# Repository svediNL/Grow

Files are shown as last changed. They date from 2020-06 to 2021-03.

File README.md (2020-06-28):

# Grow
This project uses a `Python` program in combination with an `Arduino Mega` to monitor and control factors that are involved with plant growth.

It is supposed to be used as an open-source, modular platform for growers that want to find (or create) optimal growing conditions for the growth of their plants.

The main program is started by running `python gui.py`. 
Through GUI:
- User can choose to enable/diable light as well as control intensity 
    - Manual control
    - Automatic configurable day/night cycle
- Pump is controlled with a PWM setpoint (0-255) and has external enable/disable button. 
    - The pump is interlocked (meaning it will stop) when the float switch is open, to prevent overflow or keep water at a certain level.
- Moisture value and temperature values are logged
  - Current values displayed seperatly

On the microcontroller, the following devices can be configured:
- X amount of `moisture sensor`s [Analog Input, Digital Output] 
- X amount of h-brigde `pump`s [2x PWM Outout]
- X amount of water level `float switch`es [Digital Input]
- X amount of `valve relay`s [Digital Output]
- X amount of `NTC thermistor`s [Analog Input]
- X amount of RGBW-channel `LED driver`s [PWM Output]
- Light dimming door switch [Digital Input]

## /Grow
Software suite for plant environment control.

## /Grow/app
Application directory for main application. 

### /Grow/app/config.py
Configuration of the grow setup. 
Device can be defined here and must be in accordance with the configuration installed on the arduino slave (grow.h)

### /Grow/app/gui.py
Main program.

Run in terminal using: `~/Grow/app$ python gui.py`

Dependencies: `matplotlib`, `tkinter`

### /Grow/app/comms.py
Custom library for communication with arduino.

Dependencies: `pySerial`

## /Grow/arduino

### /Grow/arduino/grow.h
Devices are defined here.

## Installing python modules
### matplotlib
`pip install matpotlib`

### pySerial
`pip install pyserial`
``

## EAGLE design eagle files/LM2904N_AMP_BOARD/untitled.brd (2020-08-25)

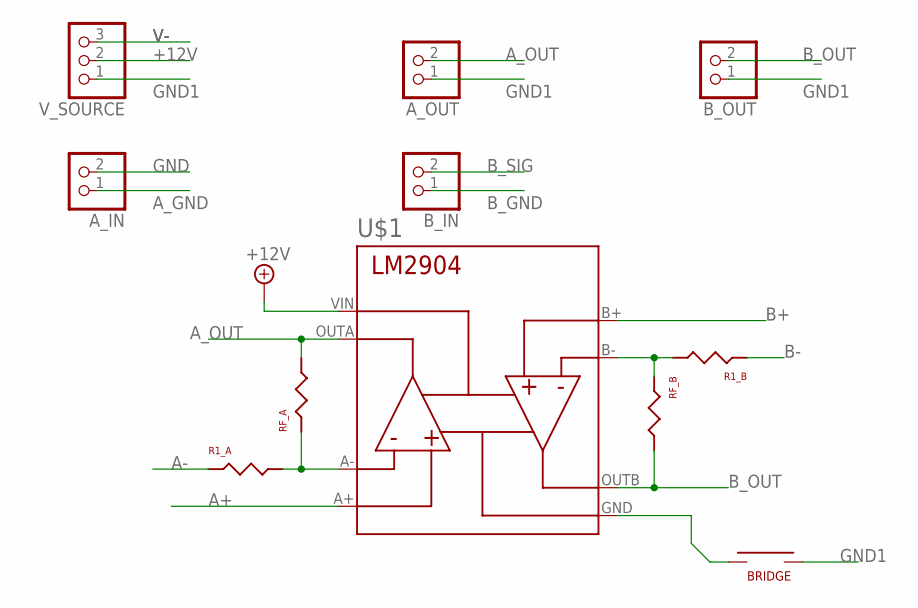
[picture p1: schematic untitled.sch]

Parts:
A_IN: PINHD-1X2; 1X02
A_OUT: PINHD-1X2; 1X02
B_IN: PINHD-1X2; 1X02
B_OUT: PINHD-1X2; 1X02
R1_A, R1_B: RESISTOR
RF_A: RESISTOR
RF_B: RESISTOR
U$1: LM2904
U$2: BRIDGE
V_SOURCE: PINHD-1X3; 1X03

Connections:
+12V: U$1.VIN, V_SOURCE.2
A+: U$1.A+
A-: R1_A.P$1
A_GND: A_IN.1
A_OUT: A_OUT.2, RF_A.P$2, U$1.OUTA
B+: U$1.B+
B-: R1_B.P$1
B_GND: B_IN.1
B_OUT: B_OUT.2, RF_B.P$2, U$1.OUTB
B_SIG: B_IN.2
GND: A_IN.2
GND1: A_OUT.1, B_OUT.1, U$2.P$2, V_SOURCE.1
unnamed: R1_B.P$2, RF_B.P$1, U$1.B-
unnamed: R1_A.P$2, RF_A.P$1, U$1.A-
V-: U$1.GND, U$2.P$1, V_SOURCE.3

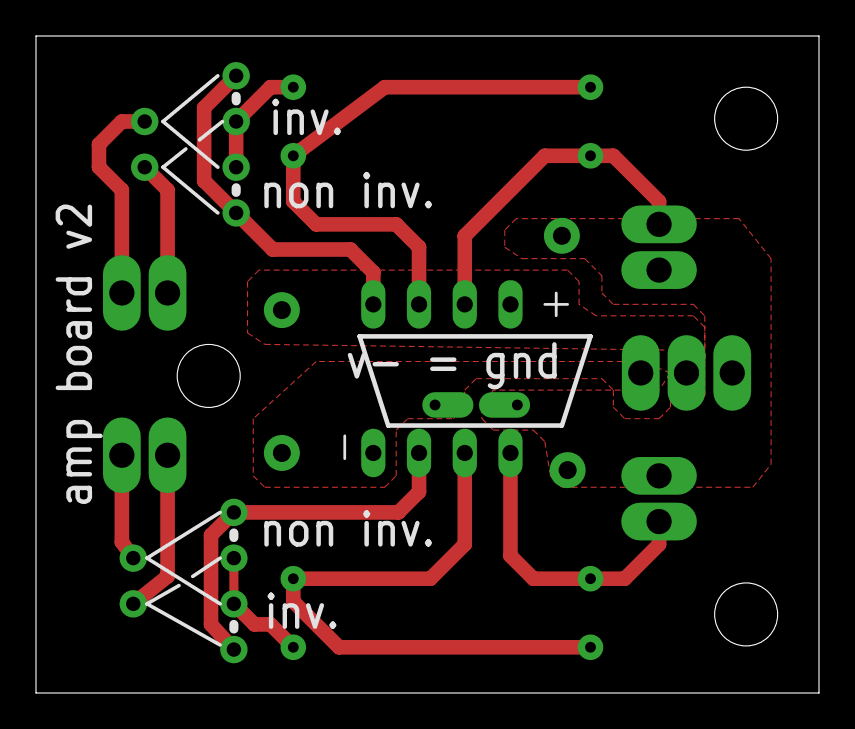
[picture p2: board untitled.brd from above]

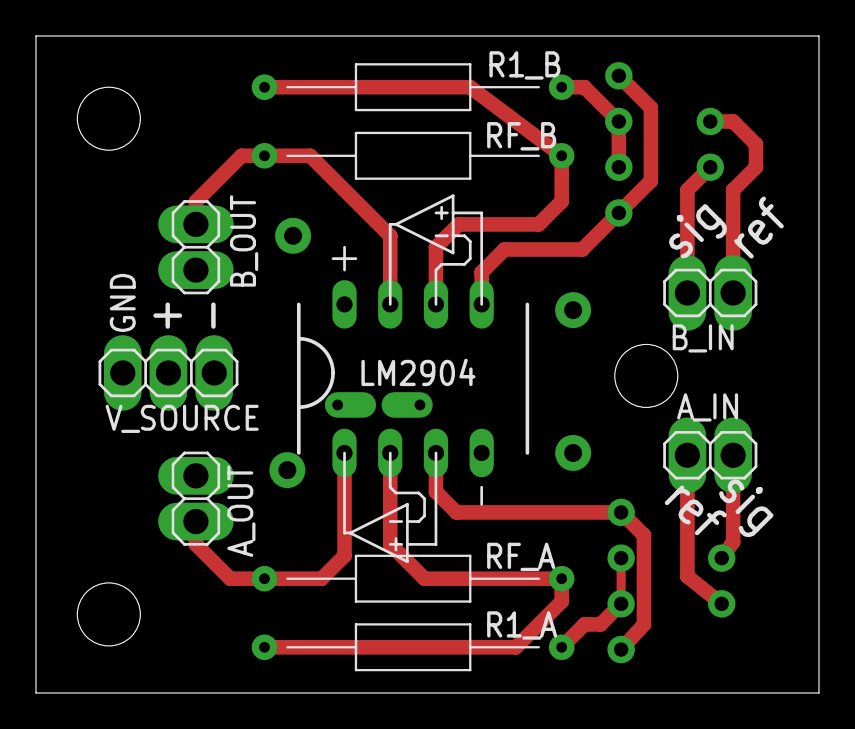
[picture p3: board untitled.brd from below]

Board: 2 copper layers, 43.5 x 36.5 mm, 11 parts (6 on the bottom side), 7 nets.

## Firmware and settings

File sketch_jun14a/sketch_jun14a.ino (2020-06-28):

// https://www.instructables.com/id/Arduino-Timer-Interrupts/

class TimeKeeper{
  public:
    void init();
    void interrupt();
    void set_time();
    String get_time();

    void set_par_clkio(long int var);
    void set_par_prescaler();
    void set_par_out_comp();
    
    void print_parameters();
    
    int hour = 22; 
    int minute= 42; 
    int second = 0;

  private:
    long int PAR_CLK_IO = 16000000; // 16 MHz
    
    int PAR_PRESCALER = 1024;
    int PAR_CS2 = 7;  // CS2=7 -> 1024 prescaler
    double PAR_CLK_T2 = double( PAR_CLK_IO ) / double(PAR_PRESCALER);
    
    int PAR_OCR2A = 243;
    double PAR_CLK_T2I = PAR_CLK_T2 / double(PAR_OCR2A+1);  // INTERRUPT TIMER FREQUENCY
    
    int freq_aprox = 64;  // PRESCALER & OCR FREQUENCY APPROXIMATIOn
    double sec_loss = 0;
    
    unsigned long int long_second = 0;
    unsigned long int long_second_prev = 0;
    int cnt_trig2 = 0;
    double sum_loss = 0;
  
} myTimeKeeper;

void TimeKeeper::init(){

      freq_aprox = floor(PAR_CLK_T2I);
      sec_loss = (1/double(freq_aprox)) - (1/double(PAR_CLK_T2I));
      
      cli();//stop interrupts
      
      // INITIALIZE REGISTERS
      TIMSK2 = 0;
      TCNT2  = 0;
      TCCR2A = 0;
      TCCR2B = 0;

      TCCR2A |= (1 << WGM21);  // turn on CTC mode
      
      GTCCR |= (1 << PSRASY); // RESET PRESCALER

      TCCR2B |= (1 << CS20);   // set pre scalar
      TCCR2B |= (1 << CS21);   // set pre scalar
      TCCR2B |= (1 << CS22);   // set pre scalar
    
      OCR2A = 243;  // set overflow value
      
      TIMSK2 |= (1 << OCIE2A);  // enable timer compare interrupt
      
      TCNT2  = 0;//initialize counter value aigain  to be sure
      sei();//allow interrupts
};

void TimeKeeper::interrupt(){
  cnt_trig2 += 1;
  sum_loss += sec_loss;
  
  if (cnt_trig2 >= freq_aprox)
  {
    // 64 Hz aproximation cycle
    long_second += 1;
    second += 1;
    cnt_trig2 = 0;

    if ((long_second%6379) == 0 && long_second>0)
    {
      Serial.println("magic leap second");
      second -= 1;
    }
    
    Serial.println(long_second);
    Serial.println(sum_loss);
  }

  if (abs(sum_loss) >=1)
  {
    // leap second
    Serial.println("leap second");
    if (sum_loss >0)
    {
      long_second += 1;
      second += 1;
      sum_loss -= 1;
    }
    else
    {
      long_second -= 1;
      second -= 1;
      sum_loss += 1;
    }
  }

  // DO HHMMSS
  if(second >= 60)
  {
    second  -= 60;
    minute  += 1;
  }
  if(minute >= 60)
  {
    minute  -= 60;
    hour    += 1;
  }
  if(hour >= 24)
  {
    hour  -= 24;
  }
  if (cnt_trig2 == 0) 
  {
    Serial.print("Time:   ");
    Serial.print(hour);
    Serial.print(":");
    Serial.print(minute);
    Serial.print(":");
    Serial.print(second);
    Serial.print("\n\r");
  }
  if (long_second == 4294967280)
  {
  // maximum amount of minutes to fit in long int 
    long_second = 0;
  }
};

void TimeKeeper::print_parameters(){
  Serial.println(PAR_CLK_T2 );
  Serial.println(PAR_CLK_T2I);
  Serial.println(freq_aprox);
  Serial.println(String(sec_loss, 10)) ;
}

void setup(){
  // put your setup code here, to run once:
  Serial.begin(9600);

  myTimeKeeper.init();
  myTimeKeeper.print_parameters();
}



ISR(TIMER2_COMPA_vect){
// ON COUNTER OUTPUT COMPARE TRIGGER
  myTimeKeeper.interrupt();
}

void loop() {
  // put your main code here, to run repeatedly:
  
}

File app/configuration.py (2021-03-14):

### USE THIS DOCUMENT TO CONFIGURE WHAT DEVICES YOU WANT TO ADD TO YOUR SETUP
## GUI WILL AUTO GENERATE BASED ON DEVICES LISTED HERE
DEBUG_MODE = False

## D E V I C E   D E F I N I T I O N
# ARDUINO
SERIAL_PORT = ""	# DEFAULT SERIAL PORT TO USE AT INIT (CAN BE EMPTY STRING IF UNKOWN)
BAUD_RATE   = 115200			# STANDARD BAUD RATE USED AT INIT

# I2C ATMOSPHERE SENSOR
ENABLE_I2C_SENSOR	= True 			# ENABLE READOUR OF SENSOR AM2320 -> HUMIDITY & TEMPERATURE

# THERMOCOUPLES
ENABLE_ANALOG_THERMO = False
NAMES_THERMO 	= []#["TC_A", "TC_B"]		# DISPLAY NAMES OF THERMOCOUPLES ->	example: NAMES_THERMO = ["ground temperature", "air temperature"]
UNIT_THERMO	= "[deg. C]"			# MEASURED UNITS OF THERMOCOUPLE

if ENABLE_I2C_SENSOR:
	NR_THERMO 		= len(NAMES_THERMO)*ENABLE_ANALOG_THERMO + 1		# NR OF THERMOCOUPLES	(CALCULATED)
	NAMES_THERMO.append("Air Temperature")
else:
	NR_THERMO 		= len(NAMES_THERMO)*ENABLE_ANALOG_THERMO		# NR OF THERMOCOUPLES	(CALCULATED)

# TEMPERATURE BUFFERS

# LED DRIVER (PWM)					
NAMES_LAMP 		= [ "LED_A" ]		# DISPLAY NAME OF LAMP UNITS ->	example: NAMES_LAMP = ["my RGBW Lamp", "my White Light", "my IR light"]													
CHANNELS_LAMP	= [ ['W'] ]			# RGBW CHANNELS FOR EACH LAMP MODULE ->	2D-array [lamp, channel] ->	example: CHANNELS_LAMP = [ ['R','G','B','W'] , ['W'], ['R'] ]		
UNIT_LAMP		= "[-]"				# MEASURED UNITS OF LAMP			
NR_LAMP 		= len(NAMES_LAMP)	# NR OF CONTROLABLE LAMPS	(CALCULATED)

# MOISTURE SENSORS
ENABLE_ANALOG_MOISTURE	= True
NAMES_MOISTURE 			= ["MOISTURE_A"]		# DISPLAY NAMES OF ANALOG RESISTIVE MOISTURE SENSORS ->	example: NAMES_MOISTURE = ["moisture small pot", "moisture big pot"]
UNIT_MOISTURE			= "[%]"					# MEASURED UNITS OF MOISTURE SENSOR

if ENABLE_I2C_SENSOR:
	NR_MOISTURE 		= len(NAMES_MOISTURE)*ENABLE_ANALOG_MOISTURE + 1		# NR OF THERMOCOUPLES	(CALCULATED)
	NAMES_MOISTURE.append("Air Humidity")
else:
	NR_MOISTURE 		= len(NAMES_MOISTURE)*ENABLE_ANALOG_MOISTURE		# NR OF THERMOCOUPLES	(CALCULATED)


# H-BRIDGE BASED PUMP (PWM, DIRECTION)
NAMES_PUMP	= ["PUMP_A"]			# PUMP DISPLAY NAMES -> ONLY ONE IS SUPPORTED ATM
UNIT_PUMP	= "[-]"								# MEASURED UNITS OF PUMP
NR_PUMP 	= len(NAMES_PUMP)	# NUMBER OF PUMPS	(CALCULATED)

# RELAYS (FANS, VALVES, PUMPS, LIGHTS)
# NAMES_RELAY	= [""," Q IN (0)", "Q WASTE (2)", "Q WATER (3)", "Q NUTR (4)", "Q OUT (5)", "FANS LAMP", "NC"]		# DISPLAY NAMES OF RELAYBOARD CHANNELS
NAMES_RELAY	= ["12V Enable"," Q IN (0)", "Q WASTE (2)", "Q WATER (3)", "Q NUTR (4)", "Q OUT (5)", "FANS LAMP", "NC"]		# DISPLAY NAMES OF RELAYS
UNIT_RELAY	= "[0/1]"
NR_RELAY 	= len(NAMES_RELAY)																								# NR OF RELAYS (CALCULATED)

# VALVE CIRCUITS
NAMES_FLOW 		= ["WATER-INPUT", "NUTR.-INPUT", "OUTPUT-WASTE", "OUTPUT-INPUT"]		# DISPLAY NAMES OF FLOW CIRCUITS
VALVES_FLOW 	= [ [1,3], [1,4], [2,5], [1,5] ]										# LIST OF VALVE INDICES TO OPEN PER FLOW CIRCUIT [CIRUIT][VALVES]
FORCE_INTERLOCK = [True, True, False, False, True]										# FORCE PUMP INTERLOCK WHEN CERTAIN FLOW INDEX IS SELECTED, LAST INDEX IS FOR WHEN FLOW CIRCOUT IS DISABLED
NR_FLOW 		= len(NAMES_FLOW)														# NR OF FLOW CIRCUITS (CALCULATED)


## T I M I N G   D E F I N I T I O N
PROGRAM_CYLCETIME	= 1000.0		#	CALL PROGRAM FUNCTION EVERY .. ms
SAMPLE_RATE 		= 5				#	GET A SAMPLE EVERY .. PROGRAM CYCLES
BUFF_LEN 			= 4096			#	SAMPLE BUFFER LENGTH
ANI_CYCLETIME 		= 10000.0		#	UPDATE PLOT / CALL ANIMATION FUNCTION EVERY .. ms


## P L O T T I N G   D E F I N I T I O N
ENABLE_DYNAMIC_RANGE_THERMO		= True
ENABLE_DYNAMIC_RANGE_LAMP		= False
ENABLE_DYNAMIC_RANGE_MOISTURE	= False
ENABLE_DYNAMIC_RANGE_PUMP		= True

DEFAULT_RANGE_THERMO 	= [10, 35]
DEFAULT_RANGE_LAMP		= [0, 255]
DEFAULT_RANGE_MOISTURE 	= [0, 100]
DEFAULT_RANGE_PUMP		= [0, 255]

PLOT_NAMES = ["OVERVIEW", "LIGHT", "MOISTURE"]
NR_PLOT = len(PLOT_NAMES)

LOG_NAME	= 'myLog.csv'


## G U I   D E S I G N
BG_MAIN			= "gray30"	#"gray93"
BG_SUB 			= "gray33"	#"gray96"
BG_SUBSUB 		= "white"	#"white"
BG_TOG_A		= BG_SUB	#"gray96"
BG_TOG_B 		= "gray44"	#"gray93"
BG_TAB 			= "gray44"	#"gray85"
BG_TAB_ACTIVE 	= BG_SUB	#"gray96"
BG_ENTRY		= "gray60"	#"white"
BG_BUTTON		= "black"
BG_CHECK		= "gray40"
BG_SEL   = "gray77"

FG_TEXT			= "white"	#"black"
FG_TEXT2			= "black"
FG_ENTRY		= "white"


THERMO_PLOT_CMAP = ['r', 'g', 'b', 'm', 'k']
MOIST_PLOT_CMAP = ['r', 'g', 'b', 'm', 'k']
PUMP_PLOT_CMAP = ['r', 'g', 'b', 'm', 'k']
LIGHT_PLOT_CMAP = ['r', 'g', 'b', 'm', 'k']

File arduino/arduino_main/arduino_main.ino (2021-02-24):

#include "grow.h" 

Grow grow;

void setup(){
  // INIT SERIAL
  Serial.begin(115200);
  grow.init(); // do all grow stuff
}

ISR(TIMER2_COMPA_vect){
// ON COUNTER OUTPUT COMPARE TRIGGER
  grow.masterClock.interrupt();
}

void loop()
// MAIN LOOP
{
  grow.doStuff();
}
 
void serialEvent(){
  grow.serialString = Serial.readStringUntil('\n');
  grow.bNewMessage = true;
}

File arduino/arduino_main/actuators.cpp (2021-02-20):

#ifndef ACTUATORS_H
#include "actuators.h"

void DigitalOutput::set(bool output){
  if(invertOutput){ digitalWrite(pin, !output); }
  else { digitalWrite(pin, output); }
  
  state= output;
}

void DigitalOutput::init(int input, String devName){
  pin = input;
  deviceName = devName;
  pinMode(pin, OUTPUT);
  state = false;
  if(invertOutput){ digitalWrite(pin, state); }
  else { digitalWrite(pin, state); }
}

void DigitalOutput::help(){
  
  Serial.print("  ");
  Serial.print(deviceName);
  Serial.print("\n\r");
  Serial.print("    - Output on pin: ");
  Serial.print(pin);
  Serial.print("\n\r");
}

void RGBWLed::init(String devName, int pinR, int pinG, int pinB, int pinW){
  pinRGBW[0] = pinR;
  pinRGBW[1] = pinG;
  pinRGBW[2] = pinB;
  pinRGBW[3] = pinW;
  deviceName = devName;

  
  for(int n=0;n<4; n++){
    if(pinRGBW[n] != -1){ pinMode(pinRGBW[n], OUTPUT); };
  }
}
void RGBWLed::help(){

  Serial.print("  ");
  Serial.print(deviceName);
  Serial.print("\n\r");

  for(int n=0;n<4; n++){
    Serial.print("   - ");
    Serial.print(cRGBW[n]);
    Serial.print(" output on pin: ");
    Serial.print(pinRGBW[n]);
    Serial.print("\n\r");
  }
}
void RGBWLed::set(RGBWenum colour, int value){
  valRGBW[colour] = value;
  if(outputEnabled) { analogWrite(pinRGBW[colour], valRGBW[colour]); }
}

void RGBWLed::enableOutput(bool output){
  outputEnabled = output;

  if(outputEnabled){
    for(int n=0; n<4; n++){
       analogWrite(pinRGBW[n], valRGBW[n]);
    }
  }
  else {
    for(int n=0; n<4; n++){
       analogWrite(pinRGBW[n], 0);
    }
  }
}

int RGBWLed::getStatus(){
  if(outputEnabled){ return valRGBW[3]; }
  else { return 0; }
}

void MotorDriver::init(byte dir, byte power, String devName){
  
  deviceName = devName;
  hBridge.pinDir = dir;
  hBridge.pinPWM = power;

  pinMode(hBridge.pinDir, OUTPUT);

  pinMode(hBridge.pinPWM, OUTPUT);

}
void MotorDriver::help(){
  Serial.print("  ");
  Serial.print(deviceName);
  Serial.print("\n\r");
  
  Serial.print("   - Motor direction on pin: ");
  Serial.print(hBridge.pinDir);
  Serial.print("\n\r");
  Serial.print("   - Motor PWM on pin: ");
  Serial.print(hBridge.pinPWM);
  Serial.print("\n\r");
}

void MotorDriver::enableOutput(bool output)
// ENABLE/DISABLE MOTOR PWM OUTPUT
{
  outputEnabled = output;

  if(output && !interlocked)
  // OUTPUT = true  &  NOT INTERLOCKED
  { analogWrite(hBridge.pinPWM, hBridge.outputPWM);}
  else
  // DISABLE BY DEFAULT
  { analogWrite(hBridge.pinPWM, 0); }
}

void MotorDriver::setPWM(int setpoint)
// SET MOTOR PWM OUTPUT
{
  hBridge.outputPWM = setpoint;

  if(outputEnabled && !interlocked)
  // OUTPUT = true  &  NOT INTERLOCKED
  { analogWrite(hBridge.pinPWM, hBridge.outputPWM); }
}

void MotorDriver::setDir(bool bDir)
// SET MOTOR H-BRIDGE DIRECTION PIN
{
  hBridge.outputDir = bDir;
  digitalWrite(hBridge.pinDir, hBridge.outputDir);
}

void MotorDriver::interlock(bool state)
// SET INTERLOCK & ACT ON INTERLOCK
{
  interlocked = state;

  bool tmp;                       // INTERLOCKED OUTPUT STATE 
  tmp = !state && outputEnabled;  // true WHEN NOT INTERLOCKED & ENABLED
  
  if(!tmp)
  // NO OUTPUT TO SET OR OUTPUT INTERLOCKED
  { analogWrite(hBridge.pinPWM, 0); }
  else 
  // ENABLED OUTPUT IS NOT INTERLOCKED
  { enableOutput(true);};
}

int MotorDriver::getStatus()
// GET DRIVE OUTPUT STATUS
{
  int tmp; 
  if(outputEnabled && !interlocked){
    if(hBridge.outputDir){ tmp = -1* hBridge.outputPWM ;}
    else {tmp = hBridge.outputPWM;}
  }
  else{ tmp = 0;}

  return tmp;
}
void MotorDriver::refresh();

#endif

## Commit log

2019-10-14 prettyfication
    print commands they way they are sent
    [config.txt]
2019-11-16 pull from raspberry
2019-12-14 Update gui.py
    Did a lot of changes on structure of packing widget
    Added program part to tkinter
    PRogram now updates current day time
2019-12-14 version 1.0
    disable printing of arduino during init
    fully implemented daylight simulator
2019-12-14 Update comms.py
    oops unsaved changes
    - disable waiting for io list printing to finish
2019-12-15 update v1.1
    Added read/write to serial interface
    Added live status frame
    Configurable animation time
2019-12-15 Update gui.py
    small fix to autoscaling of plot (visually better)
    disable signal generator
    [gui.py]
2019-12-15 added relay to gui
    added relay
    commenting
2019-12-22 v1.3
    - display input/output text with prepended </> in terminal
    - plot lamp output and pump output together with moisture level & light output
    - Added GET_PUMP & GET_LAMP command to arduino
    - Had to change default command state of -1 to enum NO_COMMAND
2019-12-28 Multiple variable plotting
    Made thermocouple variable array type -> added index parameter to get_temp()
    Added setting of relay output (fans) when setting light output
2020-01-05 v1.5
    - Tested valve sytem using relays
    - More arrays and use of configuration document
2020-01-14 Fixes
    Fixed daylight sequence
    Plot TOD instead of minutes ago
    Fix to get lamp command when door is open
    [arduino_main.ino, configuration.py, grow.h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]
2020-01-20 v1.6
    - Added door switch to lower light levels when door is opened
    - Fixed daylight mode after messing it up
    [arduino_main.ino, configuration.py, grow.h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]
2020-02-08 Fix to daylight
    Missing parametter
    [gui.py]
2020-04-05 print 4 testing
2020-05-22 Configure multiple float switches
    TODO interlock linking
2020-06-16 second timer sketch
2020-06-21 Timer seems pretty stable added modulus compensation for remaining drift
    [sketch_jun14a.ino]
2020-06-28 Implemented tomeleeping into arduino main
2020-07-25 for testing subtimers
    Added subtimers for future scheduled pumping etc on slave
2020-07-26 Restructure
    Made Grow-class so functions cane implemented to link devices (for timer to pump lijnking)
2020-07-26 so much stuff in grow that arduino_main is now almost empty
2020-07-26 Update gui.py
    Right bar is now live status + a notebook for device control (so serial & direct contro are merged) to allow for more features on one page
2020-07-28 implemented scheduler in arduino side
    Although not yet on serial comm
2020-08-21 arduino implementation of scheduler
2020-08-25 Added schematic etc for amplification board
2020-08-25 And the board ;)
    [untitled.brd, untitled.sch]
2020-09-08 arduino code fixes
    - doucle definitions in actuators.cpp/.h
    - configure one channel (white) on output because the others were using the wrong timer
    [actuators.cpp, grow.h]
2020-09-15 Plotting rework
    Do plotting without notebook & use only a single animate() thread
    [comms.py, configuration.py, gui.py]
2020-09-20 Fixes from the field
    [comms.py, configuration.py, gui.py]
2021-03-08 Update timekeeping.cpp
    disable printing of time (debugging)
2021-03-08 Add AM2315 I2C sensor
    AM2315_TEMP() -> get temperature
    AM2315_HUM() -> get humidity
    using adafruit AM2315 library
